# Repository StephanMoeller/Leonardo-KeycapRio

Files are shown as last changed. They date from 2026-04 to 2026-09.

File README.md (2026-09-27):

# v 0.8 (future)
- Fix awkward tucky thumb feeling: position adjusted and keycap swapped
- Fix case and usb cable solution
- Change mcu hole-through to backside-pads. Surface mount mcu on back side 
- (DONE) Tighter switch fittings
- Make center pcb art with segments
- (DONE) Make the diode pads smaller
- (DONE) Make better room for screws in the center
- Make the board less slippery
- Order in black core

# v 0.7
- Only choc v1 (more snappy center hole)
- Reworked center area and screws
- Top plate included
- 1.6 mm pcb (1.2 mm previously) for easier soldering as the hotswap sockets' pins were taller than 1.2 mm.
- Ordered at nextpcb (black matte) to test out another vendors ("interpretation of") black
6O7pWZk_

# v 0.6:
- Extra pinky key
- Extra thumb key
- Adjuated screw hole positions


# v 0.5:
- Choc only (v1+v2)
- Choc spaced between rows, mx spaced between columns (except inner column that is 18mm spaced)


# v 0.4:
- MiniMelf diodes
- 1mm pcb (previous was 1.6mm but the pla tenting solution started to bend)
- 2 versions: 1 for mx, 1 for choc v1 and v2 (on the same pcb)
- All screws are on the outside now to be able to mount/unmount without having to remove any switches


# v 0.3:
- M3 screw holes for mounting instead of press fitting into a case
- More tight mx footprint for better fixation of the switches


# V 0.2:
- Created with custom kicad generator
- Even traces through the squiggle for a more finished look
Untitleds

# V 0.1:
- Created with ergogen


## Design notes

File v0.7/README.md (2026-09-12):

6O7pWZk_
p0wKF9mi
lFGDnivE
woRjVouh
U_jwlm1a
Screw inserts at the bottom are for intended metal plate in the bottom

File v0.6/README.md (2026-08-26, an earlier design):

Stl: https://cad.onshape.com/documents/e97582fe212ffcc4c1cb5a1b/v/9ed9831267944d6ad736cb9b/e/22a40c86451f3a757f7858c1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









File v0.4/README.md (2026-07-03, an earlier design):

Sourcing:
- 30 minimelf diodes
- 30 choc or mx hotswap sockets, denpending on which pcb
- 1 pro micro rp2040
- A printed tent
- 11 screws + 11 heat inserts

Improvements:
- Screw holes moved to the outside of board
- Fixing screw positions north of mcu
- MiniMelf diodes instead of tht to make more room for printed switch plate
- 1mm pcb as the 1.6 made the pla printed case bend over time 

First case:




More closed case:

ast
astzt
ztgwr

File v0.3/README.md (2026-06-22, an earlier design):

Whats new?:
- Rotated switch sockets for the pinky col to prevent the board from resting on the sockets and instead resting on the edge of the pcb
- M3 screw holes for mounting instead of press fitting into a case
- More tight mx footprint for better fixation of the switches
- One half with and one without copper filling zones to see the difference
- Red pcb just to check out the color

Case: https://cad.onshape.com/documents/c9c049fe56165f77c28b246f/w/4670134b96a6073be7e06107/e/f5c39fb7f43dace8cf0abbed










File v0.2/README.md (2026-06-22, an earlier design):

Whats new?:

- Entire pcb generated in C# - allowing perfect routings in the squiggles

Issues:
- Too loose fitting on the hotswap holes (center and small support holes)
- Designed for press fit - it feels like the switches change feel when the pcb is squeezed

Untitleds



iemien

uon

t-nm

ålnien

ål

bwrb

cadas

wrp

br

r

t

a

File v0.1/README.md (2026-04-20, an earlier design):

# Leonardo KeycapRio
Leonardo KeycapRio is a custom made, single pcb, tented unibody MX keyboard. It uses squiggles on the pcb to allow bending the pcb without breaking it.

It consists of:
- rp2040 pro micro
- A single pcb
- Smd diodes
- MX Hotswap sockets

Its running my own firmware, zigmkay, which can be found here: [https://github.com/zigmkay/zigmkay_firmware](https://github.com/zigmkay/zigmkay_firmware/)

All files needed are in this repo except the onshape document which is found online here: [Onshape document for the tenting](https://cad.onshape.com/documents/2fc5b31bd095c1f6dcf1e4f8/w/506d41ccf5be44630b84bc55/e/45017851df1b112820f21494)

# Pictures

f0c6e78d-e99c-4552-b722-525dbdaa2034
d399bee0-19f2-4ae3-87b2-580c3485f8ba
cda1c4ad-42d5-49be-aa70-724a56e04ae8
a412841b-fd23-4245-b8df-11dd8428b520
7ba31df4-c509-41d3-96fa-9944f963df55
7acacc1a-34e8-4335-bca7-33bb6e089b2e
3e9439cc-7632-4e24-a68a-b5b069f46a0c



# Typing test
https://github.com/user-attachments/assets/1c0cf555-cc2f-4178-a020-7110d9704d6d

# Flexibility
The black pcb is 1.6mm thick. The white one is 1.0mm
bfdebc23-4b5a-4db6-bfac-7e51c23ea622
2951376f-daf4-4b3f-a299-c7e7881f461b

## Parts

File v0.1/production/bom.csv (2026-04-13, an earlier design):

Designator | Footprint | Quantity | Value | LCSC Part #
D1, D10, D11, D12, D13, D14, D15, D16, D17, D18, D19, D2, D20, D21, D22, D23, D24, D25, D26, D27, D28, D29, D3, D30, D4, D5, D6, D7, D8, D9 | diode_tht_sod123 | 30
MCU1 | ProMicro | 1
S1, S10, S11, S12, S13, S14, S15, S16, S17, S18, S19, S2, S20, S21, S22, S23, S24, S25, S26, S27, S28, S29, S3, S30, S4, S5, S6, S7, S8, S9 | MX | 30

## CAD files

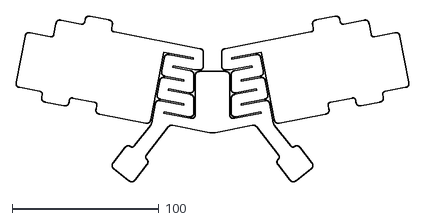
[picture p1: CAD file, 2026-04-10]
Onshape/outline.dxf
268.2 x 113.0

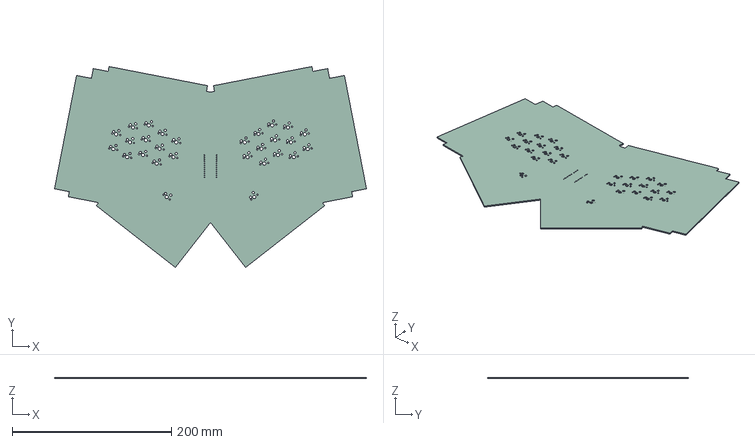
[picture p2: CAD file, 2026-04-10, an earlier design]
v0.1/kicad_poc.step
391.9 x 252.4 x 1.51 mm

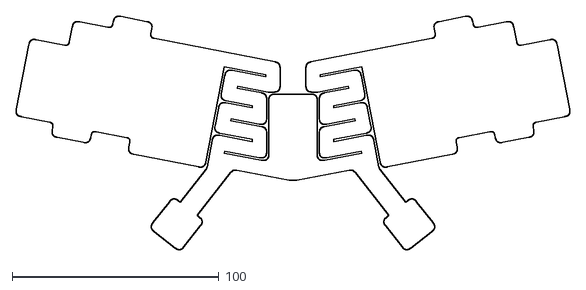
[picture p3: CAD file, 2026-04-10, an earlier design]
v0.1/Onshape/v19.dxf
268.2 x 113.0

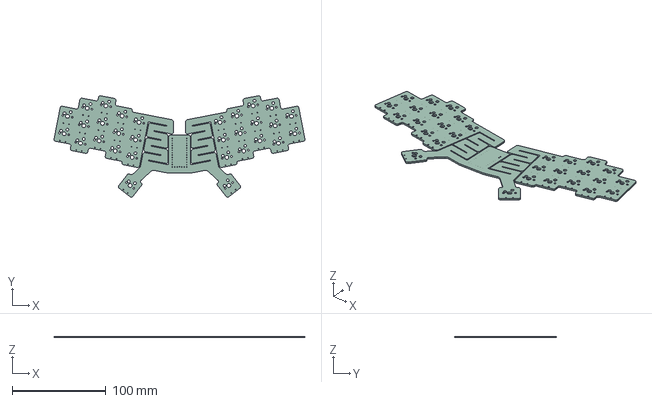
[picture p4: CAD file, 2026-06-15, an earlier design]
v0.2/pcb/output_with_fillzone.step
268.2 x 108.5 x 1.51 mm

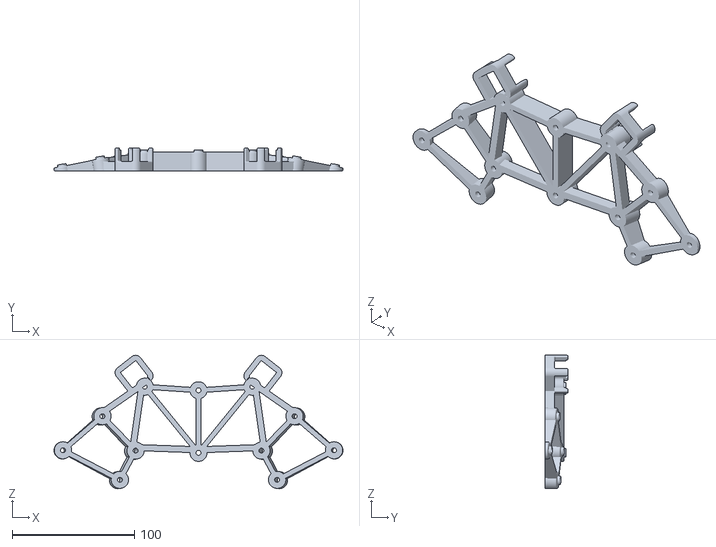
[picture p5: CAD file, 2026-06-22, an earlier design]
v0.3/upperplate_test parts - Case for leonardo v0.3.stl
236.7 x 18.9 x 109.3

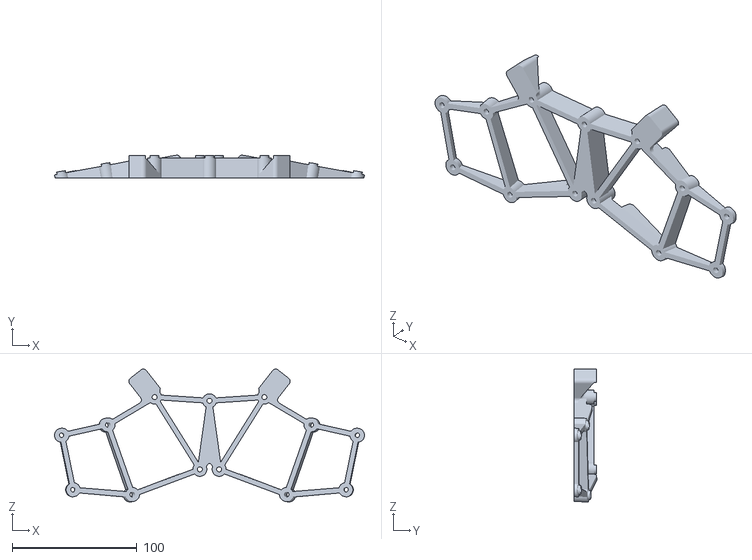
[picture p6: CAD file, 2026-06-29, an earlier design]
v0.4/Leonardo KeyCaprio 0.4 - V2 - 10 degrees tenting.stl
248.7 x 18.1 x 106.6

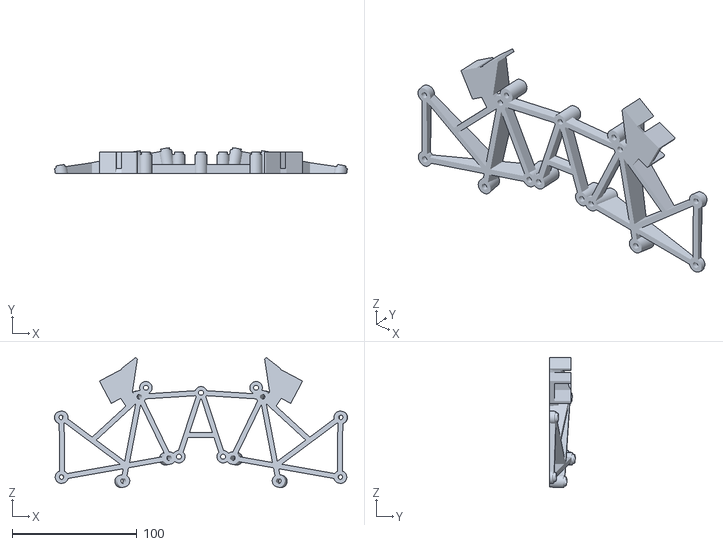
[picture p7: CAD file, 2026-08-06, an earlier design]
v0.6/Leonardo KeyCaprio v0.6 - case 1.stl
234.6 x 20.5 x 104.3

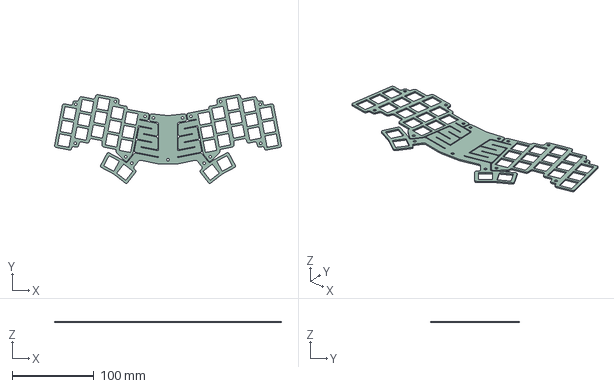
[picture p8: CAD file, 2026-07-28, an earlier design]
v0.6/output_Choc1and2_v0.6.step
277.0 x 108.4 x 1.51 mm

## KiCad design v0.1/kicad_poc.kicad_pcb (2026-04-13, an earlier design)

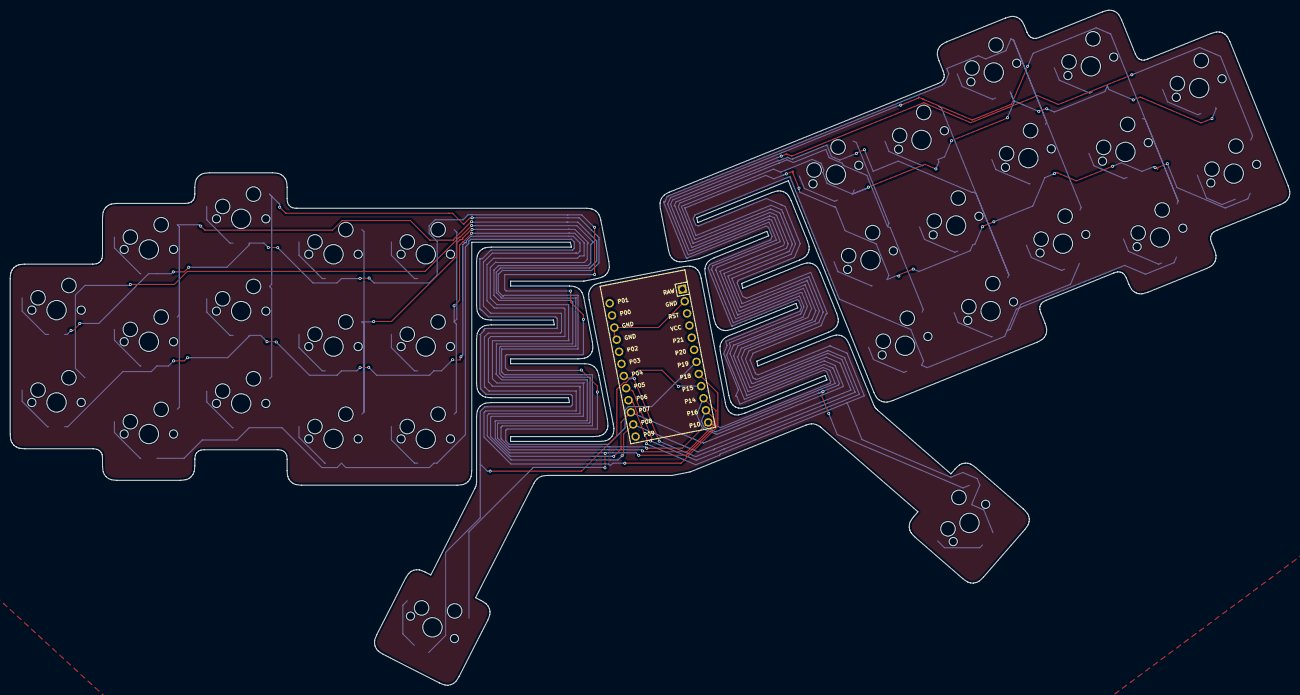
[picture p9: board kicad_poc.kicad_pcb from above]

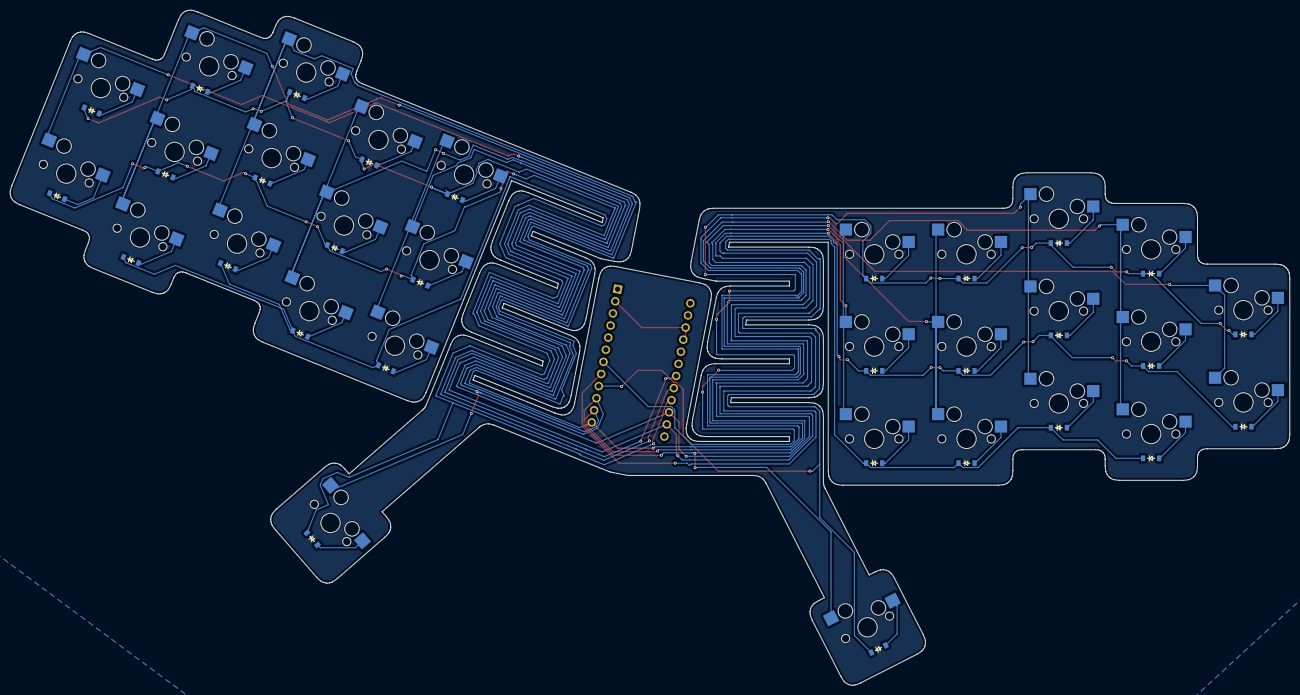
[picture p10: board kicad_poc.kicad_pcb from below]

Board: 2 copper layers, 263.4 x 138.9 mm, 61 parts (30 on the bottom side), 42 nets.

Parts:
D1, D2, D3, D4, D5, D6, D7, D8, D9, D10, D11, D12, D13, D14, D15, D16, D17, D18, D19, D20, D21, D22, D23, D24, D25, D26, D27, D28, D29, D30: diode_tht_sod123
MCU1: ProMicro
S1, S2, S3, S4, S5, S6, S7, S8, S9, S10, S11, S12, S13, S14, S15, S16, S17, S18, S19, S20, S21, S22, S23, S24, S25, S26, S27, S28, S29, S30: MX

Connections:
GND: MCU1.2, MCU1.15, MCU1.16
P4: D17.1, D20.1, D23.1, D26.1, D29.1, MCU1.19
P5: D16.1, D19.1, D22.1, D25.1, D28.1, MCU1.20
P6: D18.1, D21.1, D24.1, D27.1, D30.1, MCU1.21
P7: MCU1.22, S9.2, S10.2, S11.2, S24.2, S25.2, S26.2
P8: MCU1.23, S12.2, S13.2, S14.2, S27.2, S28.2, S29.2
P10: MCU1.12, S6.2, S7.2, S8.2, S21.2, S22.2, S23.2
P14: MCU1.10, S1.2, S2.2, S15.2, S16.2, S17.2, S30.2
P15: D3.1, D6.1, D9.1, D12.1, D15.1, MCU1.9
P16: MCU1.11, S3.2, S4.2, S5.2, S18.2, S19.2, S20.2
P18: D1.1, D4.1, D7.1, D10.1, D13.1, MCU1.8
P19: D2.1, D5.1, D8.1, D11.1, D14.1, MCU1.7
center_single: D15.2, S15.1
index_bottom: D9.2, S9.1
index_home: D10.2, S10.1
index_top: D11.2, S11.1
inner_bottom: D12.2, S12.1
inner_home: D13.2, S13.1
inner_top: D14.2, S14.1
middle_bottom: D6.2, S6.1
middle_home: D7.2, S7.1
middle_top: D8.2, S8.1
mirror_center_single: D30.2, S30.1
mirror_index_bottom: D24.2, S24.1
mirror_index_home: D25.2, S25.1
mirror_index_top: D26.2, S26.1
mirror_inner_bottom: D27.2, S27.1
mirror_inner_home: D28.2, S28.1
mirror_inner_top: D29.2, S29.1
mirror_middle_bottom: D21.2, S21.1
mirror_middle_home: D22.2, S22.1
mirror_middle_top: D23.2, S23.1
mirror_pinky_home: D16.2, S16.1
mirror_pinky_top: D17.2, S17.1
mirror_ring_bottom: D18.2, S18.1
mirror_ring_home: D19.2, S19.1
mirror_ring_top: D20.2, S20.1
pinky_home: D1.2, S1.1
pinky_top: D2.2, S2.1
ring_bottom: D3.2, S3.1
ring_home: D4.2, S4.1
ring_top: D5.2, S5.1

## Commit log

2026-04-10 all files
    [kicad_poc.kicad_pcb, kicad_poc.kicad_sch, kicad_poc.step]
2026-04-10 working state - imported pcb and outline, before doing routes
    [kicad_poc.kicad_pcb, outline.dxf]
2026-04-10 added simple single side routings on both sides
    [kicad_poc.kicad_pcb]
2026-04-10 latest with a working dxf
    [kicad_poc.kicad_pcb, v19.dxf]
2026-04-10 each side routed
    [kicad_poc.kicad_pcb]
2026-04-10 all pcb wiring done!
    [kicad_poc.kicad_pcb]
2026-04-13 latest - sent to the jlc
    [bom.csv, designators.csv, kicad_poc.kicad_pcb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]
2026-06-15 moved everything inside a v0.1 folder
    [bom.csv, designators.csv, kicad_poc.kicad_pcb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]
2026-06-15 added v0.2
    [bom.csv, designators.csv, output.kicad_pcb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]
2026-06-22 added stl case
    [upperplate_test parts - Case for leonardo v0.3.stl]
2026-06-22 Update README with v0.3 changes
    Added details about M3 screw holes and tighter MX footprint.
2026-06-29 added and rearranged pcbs
    [bom.csv, designators.csv, output.kicad_pcb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]
2026-06-29 added stl for tenting
    [Leonardo KeyCaprio 0.4 - V2 - 10 degrees tenting.stl]
2026-07-28 added v0.5 and v0.6 productions
    [bom.csv, designators.csv, output_Choc1and2.kicad_pcb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]
2026-08-06 added stl
    [Leonardo KeyCaprio v0.6 - case 1.stl]
2026-09-11 Update README with new features and fixes
    Added fixes for case and USB cable solution, surface mount MCU, and production in black core PCB.
2026-09-11 Add tighter switch fittings to README
2026-09-12 Update README with images and screw insert note
    Added images and a note about screw inserts for the metal plate.
2026-09-20 Make diode pads smaller in README
    Reduce the size of the diode pads in the design.
2026-09-20 Remove future production details from README
    Removed future production plans for black core PCB.
2026-09-22 Add note to make the board less slippery
2026-09-27 Update README with completed diode pad adjustment
2026-09-27 Remove completed task about screw space in center
